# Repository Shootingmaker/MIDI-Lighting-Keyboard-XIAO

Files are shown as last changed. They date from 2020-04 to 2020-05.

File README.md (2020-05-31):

# MIDI-Lighting-Keyboard-XIAO  
  
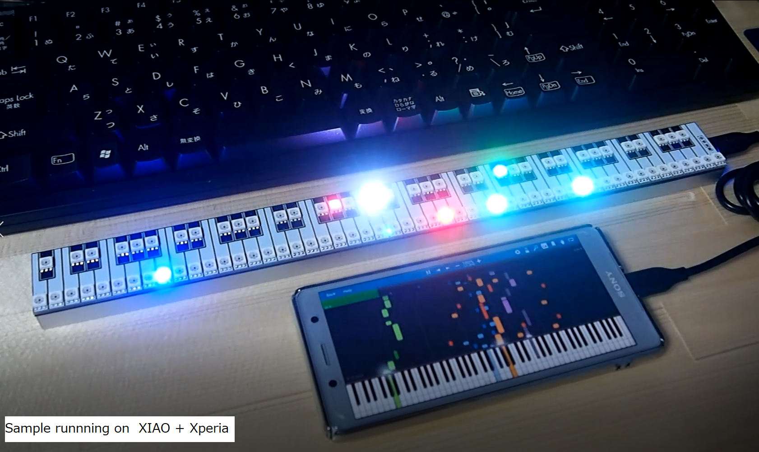
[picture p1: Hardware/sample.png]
Sample
 

(https://www.youtube.com/watch?v=Ko7Av_kq-fI)
This repository for like this video.  
  
1.[Board setting]  
File ->>> Enviroment ->>> add URL  
https://files.seeedstudio.com/arduino/package_seeeduino_boards_index.json  
 
 [Tool ->>> Setting]   
Board : Seed Studio XIAO  
USB stack : Arduino  
Debug:off  
 
2.[Library Install]  
FastLED 3.3.3 "5kft" fork.  
Tools -> Library manager.  
https://github.com/5kft/FastLED/tree/platform-xiao  
 
Arduiono MIDI 5.0  
Tools -> Library manager.  
https://github.com/FortySevenEffects/arduino_midi_library  
 
Arduino USB-MIDI  
Tools -> Library manager.  
https://github.com/lathoub/Arduino-USBMIDI  
 
MIDIUSB  
Tools -> Library manager.  
https://github.com/arduino-libraries/MIDIUSB  
 
3.[Over write "buffer memory" & "RunningStatus" setting.]  
 
 "midi_Settings.h" over write or  USE static  const  
 -> static const unsigned SysExMaxSize = 10240;  // more is better.  
 -> static const bool UseRunningStatus = true;  

4.[HARDWARE Wireing to LED (SK9822 or APA102)]  
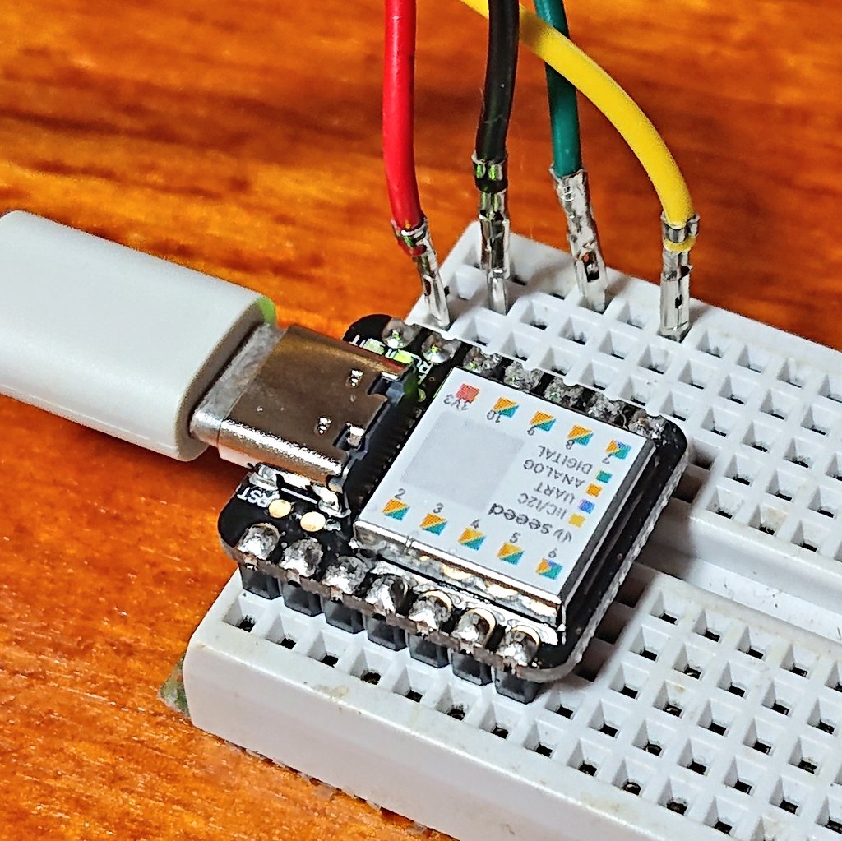
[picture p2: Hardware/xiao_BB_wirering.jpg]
pin

  
 5V    with Capacitor 100uF is Better.  
 SDI(Serial DATA In = MOSI) is  Pin:10(XIAO)  
 CKI(Clock In)  is  Pin:8(XIAO)  
 GND

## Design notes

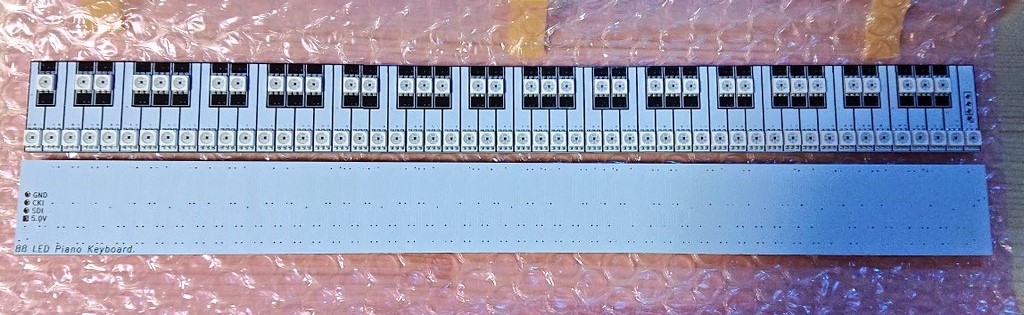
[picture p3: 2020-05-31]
Hardware/PCB_pic.jpg

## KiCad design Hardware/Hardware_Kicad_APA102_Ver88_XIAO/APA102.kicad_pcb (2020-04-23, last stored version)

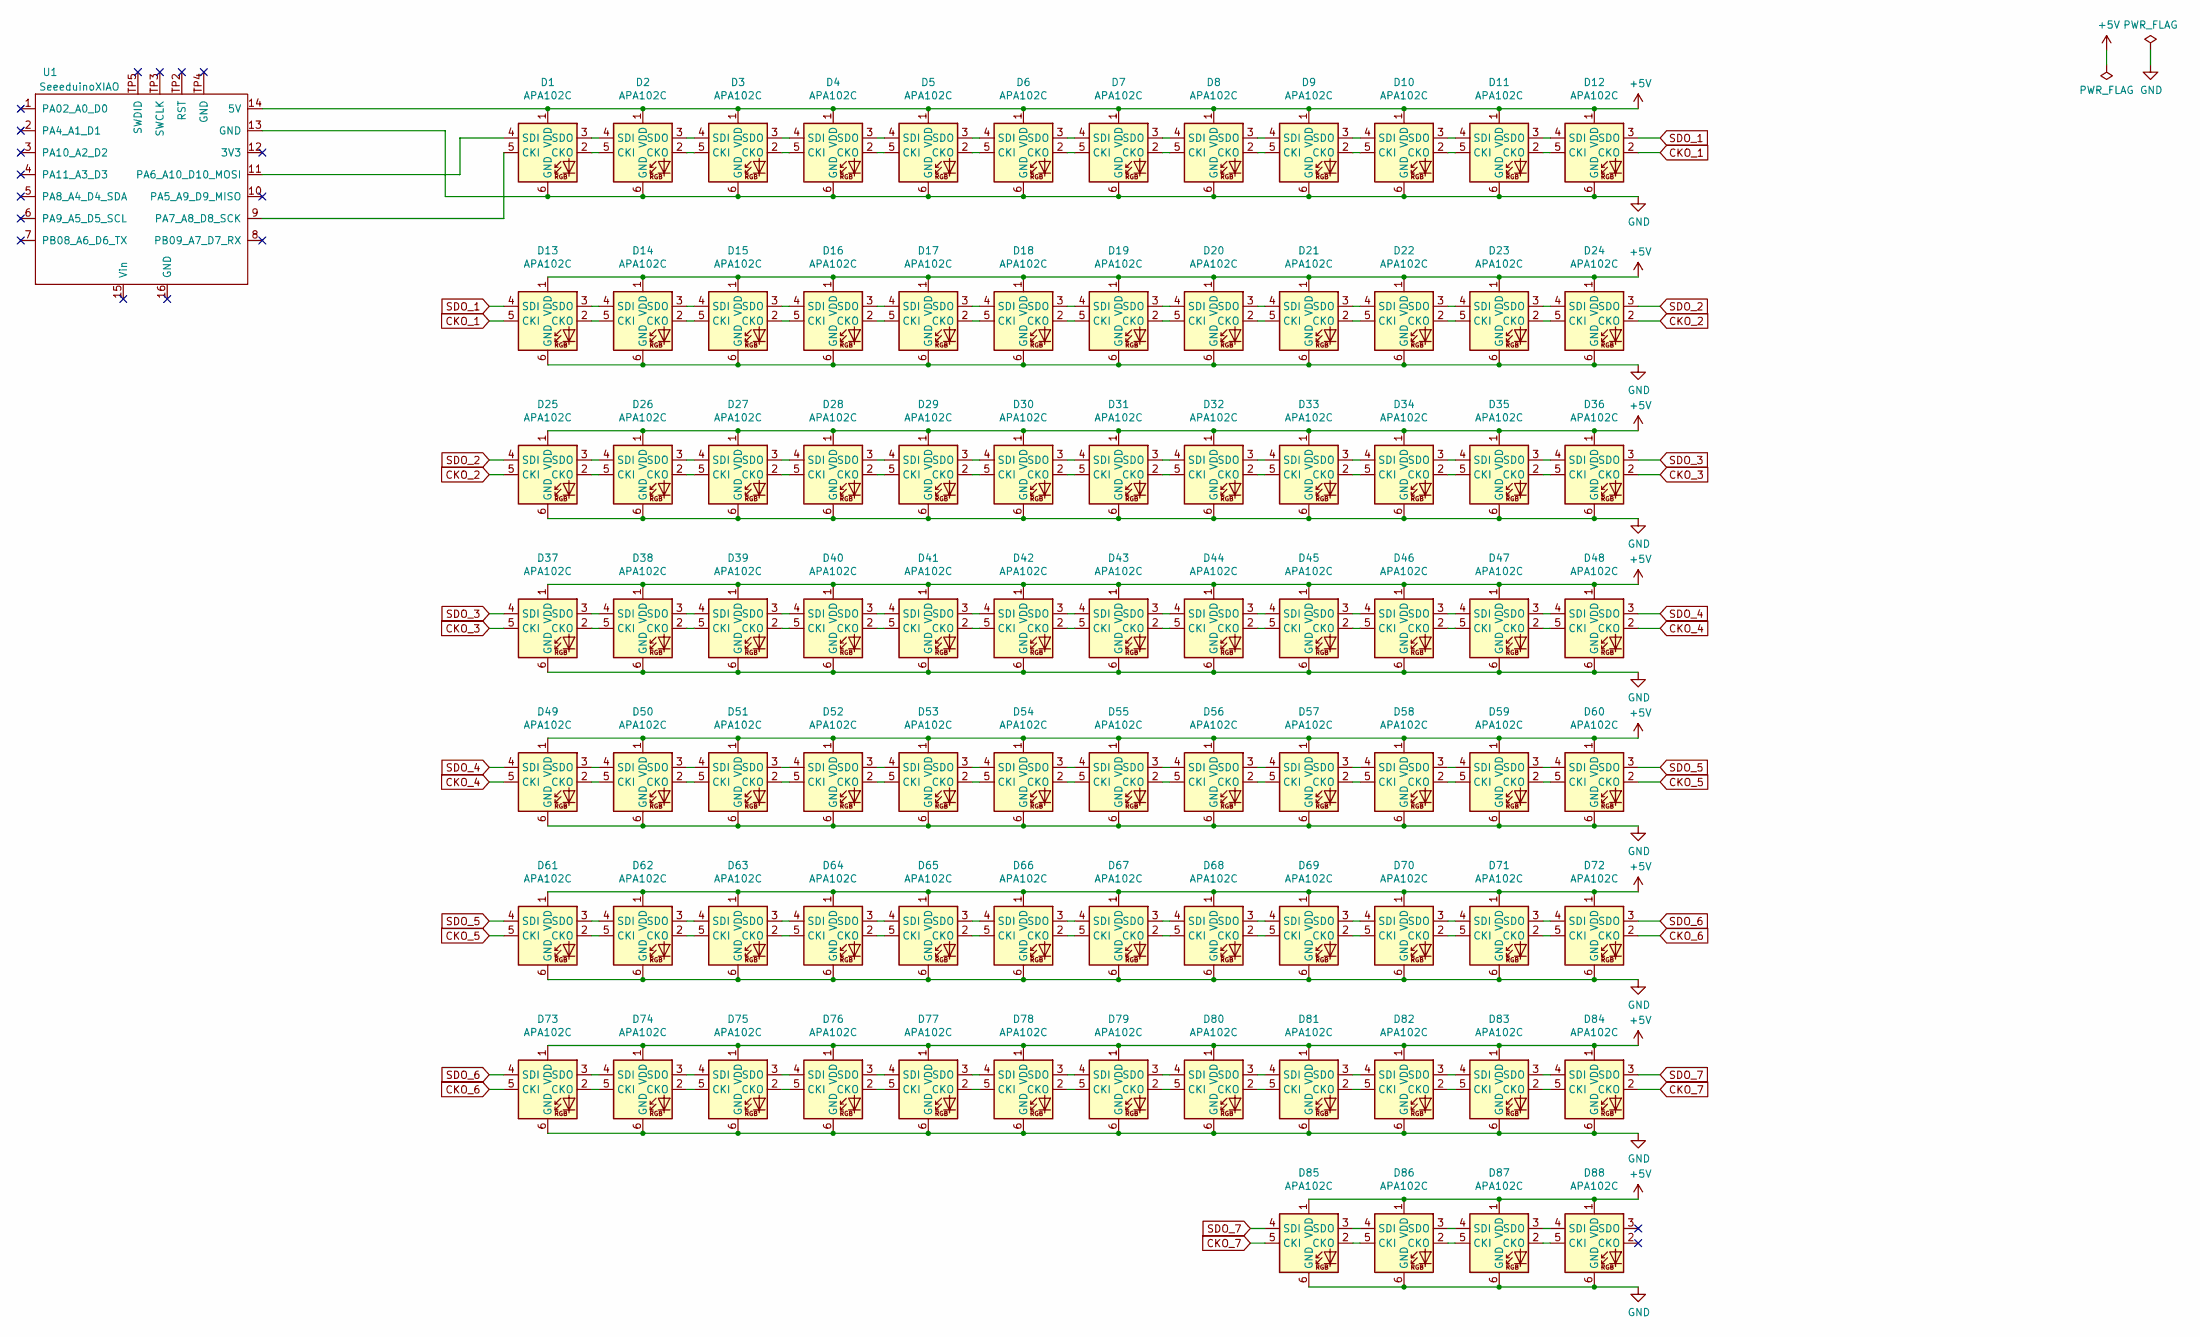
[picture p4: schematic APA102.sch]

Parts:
D1, D2, D3, D4, D5, D6, D7, D8, D9, D10, D11, D12, D13, D14, D15, D16, D17, D18, D19, D20, D21, D22, D23, D24, D25, D26, D27, D28, D29, D30, D31, D32, D33, D34, D35, D36, D37, D38, D39, D40, D41, D42, D43, D44, D45, D46, D47, D48, D49, D50, D51, D52, D53, D54, D55, D56, D57, D58, D59, D60, D61, D62, D63, D64, D65, D66, D67, D68, D69, D70, D71, D72, D73, D74, D75, D76, D77, D78, D79, D80, D81, D82, D83, D84, D85, D86, D87, D88: APA102C; LED_RGB_5050-6B
U1: SeeeduinoXIAO; Seeeduino XIAO-MOUDLE14P-2.54-21X17.8MM

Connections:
+5V: D1.1 (VDD), D2.1 (VDD), D3.1 (VDD), D4.1 (VDD), D5.1 (VDD), D6.1 (VDD), D7.1 (VDD), D8.1 (VDD), D9.1 (VDD), D10.1 (VDD), D11.1 (VDD), D12.1 (VDD), D13.1 (VDD), D14.1 (VDD), D15.1 (VDD), D16.1 (VDD), D17.1 (VDD), D18.1 (VDD), D19.1 (VDD), D20.1 (VDD), D21.1 (VDD), D22.1 (VDD), D23.1 (VDD), D24.1 (VDD), D25.1 (VDD), D26.1 (VDD), D27.1 (VDD), D28.1 (VDD), D29.1 (VDD), D30.1 (VDD), D31.1 (VDD), D32.1 (VDD), D33.1 (VDD), D34.1 (VDD), D35.1 (VDD), D36.1 (VDD), D37.1 (VDD), D38.1 (VDD), D39.1 (VDD), D40.1 (VDD), D41.1 (VDD), D42.1 (VDD), D43.1 (VDD), D44.1 (VDD), D45.1 (VDD), D46.1 (VDD), D47.1 (VDD), D48.1 (VDD), D49.1 (VDD), D50.1 (VDD), D51.1 (VDD), D52.1 (VDD), D53.1 (VDD), D54.1 (VDD), D55.1 (VDD), D56.1 (VDD), D57.1 (VDD), D58.1 (VDD), D59.1 (VDD), D60.1 (VDD), D61.1 (VDD), D62.1 (VDD), D63.1 (VDD), D64.1 (VDD), D65.1 (VDD), D66.1 (VDD), D67.1 (VDD), D68.1 (VDD), D69.1 (VDD), D70.1 (VDD), D71.1 (VDD), D72.1 (VDD), D73.1 (VDD), D74.1 (VDD), D75.1 (VDD), D76.1 (VDD), D77.1 (VDD), D78.1 (VDD), D79.1 (VDD), D80.1 (VDD), D81.1 (VDD), D82.1 (VDD), D83.1 (VDD), D84.1 (VDD), D85.1 (VDD), D86.1 (VDD), D87.1 (VDD), D88.1 (VDD), U1.14 (5V); also elsewhere on the board
CKO_1: D12.2 (CKO), D13.5 (CKI)
CKO_2: D24.2 (CKO), D25.5 (CKI)
CKO_3: D36.2 (CKO), D37.5 (CKI)
CKO_4: D48.2 (CKO), D49.5 (CKI)
CKO_5: D60.2 (CKO), D61.5 (CKI)
CKO_6: D72.2 (CKO), D73.5 (CKI)
CKO_7: D84.2 (CKO), D85.5 (CKI)
GND: D1.6 (GND), D2.6 (GND), D3.6 (GND), D4.6 (GND), D5.6 (GND), D6.6 (GND), D7.6 (GND), D8.6 (GND), D9.6 (GND), D10.6 (GND), D11.6 (GND), D12.6 (GND), D13.6 (GND), D14.6 (GND), D15.6 (GND), D16.6 (GND), D17.6 (GND), D18.6 (GND), D19.6 (GND), D20.6 (GND), D21.6 (GND), D22.6 (GND), D23.6 (GND), D24.6 (GND), D25.6 (GND), D26.6 (GND), D27.6 (GND), D28.6 (GND), D29.6 (GND), D30.6 (GND), D31.6 (GND), D32.6 (GND), D33.6 (GND), D34.6 (GND), D35.6 (GND), D36.6 (GND), D37.6 (GND), D38.6 (GND), D39.6 (GND), D40.6 (GND), D41.6 (GND), D42.6 (GND), D43.6 (GND), D44.6 (GND), D45.6 (GND), D46.6 (GND), D47.6 (GND), D48.6 (GND), D49.6 (GND), D50.6 (GND), D51.6 (GND), D52.6 (GND), D53.6 (GND), D54.6 (GND), D55.6 (GND), D56.6 (GND), D57.6 (GND), D58.6 (GND), D59.6 (GND), D60.6 (GND), D61.6 (GND), D62.6 (GND), D63.6 (GND), D64.6 (GND), D65.6 (GND), D66.6 (GND), D67.6 (GND), D68.6 (GND), D69.6 (GND), D70.6 (GND), D71.6 (GND), D72.6 (GND), D73.6 (GND), D74.6 (GND), D75.6 (GND), D76.6 (GND), D77.6 (GND), D78.6 (GND), D79.6 (GND), D80.6 (GND), D81.6 (GND), D82.6 (GND), D83.6 (GND), D84.6 (GND), D85.6 (GND), D86.6 (GND), D87.6 (GND), D88.6 (GND), U1.13 (GND); also elsewhere on the board
unnamed: D1.2 (CKO), D2.5 (CKI)
unnamed: D1.3 (SDO), D2.4 (SDI)
unnamed 11: D1.4 (SDI), U1.11 (PA6_A10_D10_MOSI); also elsewhere on the board
unnamed 12: D1.5 (CKI), U1.9 (PA7_A8_D8_SCK); also elsewhere on the board
unnamed: D2.2 (CKO), D3.5 (CKI)
unnamed: D2.3 (SDO), D3.4 (SDI)
unnamed: D3.2 (CKO), D4.5 (CKI)
unnamed: D3.3 (SDO), D4.4 (SDI)
unnamed: D4.2 (CKO), D5.5 (CKI)
unnamed: D4.3 (SDO), D5.4 (SDI)
unnamed: D5.2 (CKO), D6.5 (CKI)
unnamed: D5.3 (SDO), D6.4 (SDI)
unnamed: D6.2 (CKO), D7.5 (CKI)
unnamed: D6.3 (SDO), D7.4 (SDI)
unnamed: D7.2 (CKO), D8.5 (CKI)
unnamed: D7.3 (SDO), D8.4 (SDI)
unnamed: D8.2 (CKO), D9.5 (CKI)
unnamed: D8.3 (SDO), D9.4 (SDI)
unnamed: D10.2 (CKO), D11.5 (CKI)
unnamed: D10.3 (SDO), D11.4 (SDI)
unnamed: D9.3 (SDO), D10.4 (SDI)
unnamed: D9.2 (CKO), D10.5 (CKI)
unnamed: D11.2 (CKO), D12.5 (CKI)
unnamed: D11.3 (SDO), D12.4 (SDI)
unnamed: D13.2 (CKO), D14.5 (CKI)
unnamed: D13.3 (SDO), D14.4 (SDI)
unnamed: D14.2 (CKO), D15.5 (CKI)
unnamed: D14.3 (SDO), D15.4 (SDI)
unnamed: D15.2 (CKO), D16.5 (CKI)
unnamed: D15.3 (SDO), D16.4 (SDI)
unnamed: D16.2 (CKO), D17.5 (CKI)
unnamed: D16.3 (SDO), D17.4 (SDI)
unnamed: D17.2 (CKO), D18.5 (CKI)
unnamed: D17.3 (SDO), D18.4 (SDI)
unnamed: D18.2 (CKO), D19.5 (CKI)
unnamed: D18.3 (SDO), D19.4 (SDI)
unnamed: D19.2 (CKO), D20.5 (CKI)
unnamed: D19.3 (SDO), D20.4 (SDI)
unnamed: D20.2 (CKO), D21.5 (CKI)
unnamed: D20.3 (SDO), D21.4 (SDI)
unnamed: D21.2 (CKO), D22.5 (CKI)
unnamed: D21.3 (SDO), D22.4 (SDI)
unnamed: D22.2 (CKO), D23.5 (CKI)
unnamed: D22.3 (SDO), D23.4 (SDI)
unnamed: D23.2 (CKO), D24.5 (CKI)
unnamed: D23.3 (SDO), D24.4 (SDI)
unnamed: D25.2 (CKO), D26.5 (CKI)
unnamed: D25.3 (SDO), D26.4 (SDI)
unnamed: D26.2 (CKO), D27.5 (CKI)
unnamed: D26.3 (SDO), D27.4 (SDI)
unnamed: D27.2 (CKO), D28.5 (CKI)
unnamed: D27.3 (SDO), D28.4 (SDI)
unnamed: D28.2 (CKO), D29.5 (CKI)
unnamed: D28.3 (SDO), D29.4 (SDI)
unnamed: D29.2 (CKO), D30.5 (CKI)
unnamed: D29.3 (SDO), D30.4 (SDI)
unnamed: D30.2 (CKO), D31.5 (CKI)
unnamed: D30.3 (SDO), D31.4 (SDI)
unnamed: D31.2 (CKO), D32.5 (CKI)
unnamed: D31.3 (SDO), D32.4 (SDI)
unnamed: D32.2 (CKO), D33.5 (CKI)
unnamed: D32.3 (SDO), D33.4 (SDI)
unnamed: D33.2 (CKO), D34.5 (CKI)
unnamed: D33.3 (SDO), D34.4 (SDI)
unnamed: D34.2 (CKO), D35.5 (CKI)
unnamed: D34.3 (SDO), D35.4 (SDI)
unnamed: D35.2 (CKO), D36.5 (CKI)
unnamed: D35.3 (SDO), D36.4 (SDI)
unnamed: D37.2 (CKO), D38.5 (CKI)
unnamed: D37.3 (SDO), D38.4 (SDI)
unnamed: D38.2 (CKO), D39.5 (CKI)
unnamed: D38.3 (SDO), D39.4 (SDI)
unnamed: D39.2 (CKO), D40.5 (CKI)
unnamed: D39.3 (SDO), D40.4 (SDI)
unnamed: D40.2 (CKO), D41.5 (CKI)
unnamed: D40.3 (SDO), D41.4 (SDI)
unnamed: D41.2 (CKO), D42.5 (CKI)
unnamed: D41.3 (SDO), D42.4 (SDI)
unnamed: D42.2 (CKO), D43.5 (CKI)
unnamed: D42.3 (SDO), D43.4 (SDI)
unnamed: D43.2 (CKO), D44.5 (CKI)
unnamed: D43.3 (SDO), D44.4 (SDI)
unnamed: D44.2 (CKO), D45.5 (CKI)
unnamed: D44.3 (SDO), D45.4 (SDI)
unnamed: D45.2 (CKO), D46.5 (CKI)
unnamed: D45.3 (SDO), D46.4 (SDI)
unnamed: D46.2 (CKO), D47.5 (CKI)
unnamed: D46.3 (SDO), D47.4 (SDI)
unnamed: D47.2 (CKO), D48.5 (CKI)
unnamed: D47.3 (SDO), D48.4 (SDI)
unnamed: D49.2 (CKO), D50.5 (CKI)
unnamed: D49.3 (SDO), D50.4 (SDI)
unnamed: D50.2 (CKO), D51.5 (CKI)
unnamed: D50.3 (SDO), D51.4 (SDI)
unnamed: D51.2 (CKO), D52.5 (CKI)
unnamed: D51.3 (SDO), D52.4 (SDI)
unnamed: D52.2 (CKO), D53.5 (CKI)
unnamed: D52.3 (SDO), D53.4 (SDI)
unnamed: D53.2 (CKO), D54.5 (CKI)
unnamed: D53.3 (SDO), D54.4 (SDI)
unnamed: D54.2 (CKO), D55.5 (CKI)
unnamed: D54.3 (SDO), D55.4 (SDI)
unnamed: D55.2 (CKO), D56.5 (CKI)
unnamed: D55.3 (SDO), D56.4 (SDI)
unnamed: D56.2 (CKO), D57.5 (CKI)
unnamed: D56.3 (SDO), D57.4 (SDI)
unnamed: D57.2 (CKO), D58.5 (CKI)
unnamed: D57.3 (SDO), D58.4 (SDI)
unnamed: D58.2 (CKO), D59.5 (CKI)
unnamed: D58.3 (SDO), D59.4 (SDI)
unnamed: D59.2 (CKO), D60.5 (CKI)
unnamed: D59.3 (SDO), D60.4 (SDI)
unnamed: D61.2 (CKO), D62.5 (CKI)
unnamed: D61.3 (SDO), D62.4 (SDI)
unnamed: D62.2 (CKO), D63.5 (CKI)
unnamed: D62.3 (SDO), D63.4 (SDI)
unnamed: D63.2 (CKO), D64.5 (CKI)
unnamed: D63.3 (SDO), D64.4 (SDI)
unnamed: D64.2 (CKO), D65.5 (CKI)
unnamed: D64.3 (SDO), D65.4 (SDI)
unnamed: D65.2 (CKO), D66.5 (CKI)
unnamed: D65.3 (SDO), D66.4 (SDI)
unnamed: D66.2 (CKO), D67.5 (CKI)
unnamed: D66.3 (SDO), D67.4 (SDI)
unnamed: D67.2 (CKO), D68.5 (CKI)
unnamed: D67.3 (SDO), D68.4 (SDI)
unnamed: D68.2 (CKO), D69.5 (CKI)
unnamed: D68.3 (SDO), D69.4 (SDI)
unnamed: D69.2 (CKO), D70.5 (CKI)
unnamed: D69.3 (SDO), D70.4 (SDI)
unnamed: D70.2 (CKO), D71.5 (CKI)
unnamed: D70.3 (SDO), D71.4 (SDI)
unnamed: D71.2 (CKO), D72.5 (CKI)
unnamed: D71.3 (SDO), D72.4 (SDI)
unnamed: D73.2 (CKO), D74.5 (CKI)
unnamed: D73.3 (SDO), D74.4 (SDI)
unnamed: D74.2 (CKO), D75.5 (CKI)
unnamed: D74.3 (SDO), D75.4 (SDI)
unnamed: D75.2 (CKO), D76.5 (CKI)
unnamed: D75.3 (SDO), D76.4 (SDI)
unnamed: D76.2 (CKO), D77.5 (CKI)
unnamed: D76.3 (SDO), D77.4 (SDI)
unnamed: D77.2 (CKO), D78.5 (CKI)
unnamed: D77.3 (SDO), D78.4 (SDI)
unnamed: D78.2 (CKO), D79.5 (CKI)
unnamed: D78.3 (SDO), D79.4 (SDI)
unnamed: D79.2 (CKO), D80.5 (CKI)
unnamed: D79.3 (SDO), D80.4 (SDI)
unnamed: D80.2 (CKO), D81.5 (CKI)
unnamed: D80.3 (SDO), D81.4 (SDI)
unnamed: D81.2 (CKO), D82.5 (CKI)
unnamed: D81.3 (SDO), D82.4 (SDI)
unnamed: D82.2 (CKO), D83.5 (CKI)
unnamed: D82.3 (SDO), D83.4 (SDI)
unnamed: D83.2 (CKO), D84.5 (CKI)
unnamed: D83.3 (SDO), D84.4 (SDI)
unnamed: D85.2 (CKO), D86.5 (CKI)
unnamed: D85.3 (SDO), D86.4 (SDI)
unnamed: D86.2 (CKO), D87.5 (CKI)
unnamed: D86.3 (SDO), D87.4 (SDI)
unnamed: D87.2 (CKO), D88.5 (CKI)
unnamed: D87.3 (SDO), D88.4 (SDI)
SDO_1: D12.3 (SDO), D13.4 (SDI)
SDO_2: D24.3 (SDO), D25.4 (SDI)
SDO_3: D36.3 (SDO), D37.4 (SDI)
SDO_4: D48.3 (SDO), D49.4 (SDI)
SDO_5: D60.3 (SDO), D61.4 (SDI)
SDO_6: D72.3 (SDO), D73.4 (SDI)
SDO_7: D84.3 (SDO), D85.4 (SDI)

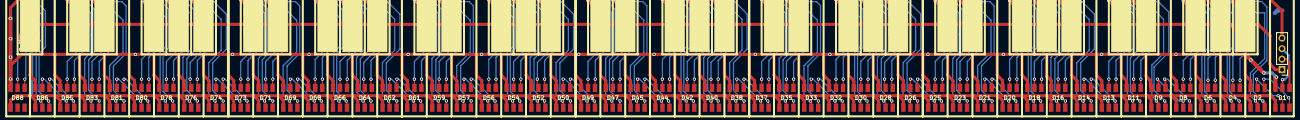
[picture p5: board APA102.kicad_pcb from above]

Board: 2 copper layers, 89 parts (0 on the bottom side), 178 nets.

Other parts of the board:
J1: Conn_01x04_Female; PinHeader_1x04_P2.54mm_Vertical

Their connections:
+5V: J1.1; also elsewhere on the board
GND: J1.4; also elsewhere on the board
unnamed 11: J1.2; also elsewhere on the board
unnamed 12: J1.3; also elsewhere on the board

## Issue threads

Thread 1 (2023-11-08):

No hardware SPI pins defined.  All SPI access will default to bitbanged output

huster-songtao, 2023-11-08:
open MIDI-Lighting-Keyboard_APA102_XIAO_octave_shift_plus_PCB_Revers.ino and modify the code:

```
/* -----------------------------------------------------------------------------
[MIDI Lighting Keyboard Project.]
Kotohiro Masuda. 2020/4/23
-----------------------------------------------------------------------------*/
/*
1.[Board setting]
File ->>> Enviroment ->>> add URL
https://files.seeedstudio.com/arduino/package_seeeduino_boards_index.json

 [Tool ->>> Setting]
Board : Seed Studio XIAO
USB stack : Arduino
Debug:off

2.[Library Install]
FastLED 3.3.3 "5kft" fork.
Tools -> Library manager.
https://github.com/5kft/FastLED/tree/platform-xiao

Arduiono MIDI 5.0
Tools -> Library manager.
https://github.com/FortySevenEffects/arduino_midi_library

Arduino USB-MIDI
Tools -> Library manager.
https://github.com/lathoub/Arduino-USBMIDI

MIDIUSB
Tools -> Library manager.
https://github.com/arduino-libraries/MIDIUSB

3.[Over write "buffer memory" & "RunningStatus" setting.]

 "midi_Settings.h" over write or  USE static  const
 -> static const unsigned SysExMaxSize = 10240;
 -> static const bool UseRunningStatus = true;

4.[HARDWARE Wireing to LED(APA102)]
 5V    with Capacitor 100uF is Better.
 GND
 MOSI is  10
 CLK  is  8

-----------------------------------------------------------------------------*/
static  const  unsigned SysExMaxSize = 1024*28 ;  //1024*24K
static  const  bool UseRunningStatus = true ;

int FastLEDSet_Ch[128];          // Map of Who(channel) use LED?
int octave_shift= 2 *12;           // Shift Octave, if few LEDs. "1"octave=12LEDs.
int Reverse = 127+5 ;

// -----------------------------------------------------------------------------
#include <FastLED.h>

// How many leds in your strip?
#define NUM_LEDS 128
#define DATA_PIN 10
#define CLOCK_PIN 8
#define BRIGHTNESS 24

// Define the array of leds
CRGB leds[NUM_LEDS];

int delayval = 2; // delay for test

// -----------------------------------------------------------------------------

// -----------------------------------------------------------------------------
// LED Blink control.

void handleNoteOn(byte channel, byte pitch, byte velocity)
{
  if (velocity == 0) {  // 　Note ON "Velocity = 0" is NOTE Off.
    leds[pitch].setRGB( 0, 0, 0);
  } else {
    switch (channel) {  //  Select Ch       //　Blink velocity power!
      case 1:
        leds[Reverse-pitch-octave_shift] = CRGB::Green;
        FastLEDSet_Ch[Reverse-pitch-octave_shift]=1;
        break;
      case 2:
        leds[Reverse-pitch-octave_shift] = CRGB::Blue;
        FastLEDSet_Ch[Reverse-pitch-octave_shift]=2;
        break;
      case 3:
        leds[Reverse-pitch-octave_shift] = CRGB::Red;
        FastLEDSet_Ch[Reverse-pitch-octave_shift]=3;
        break;
      case 4:
        leds[Reverse-pitch-octave_shift] = CRGB::Yellow;
        FastLEDSet_Ch[Reverse-pitch-octave_shift]=4;
        break;
      case 5:
        leds[Reverse-pitch-octave_shift] = CRGB::Orange;
        FastLEDSet_Ch[Reverse-pitch-octave_shift]=5;
        break;
      case 6:
        leds[Reverse-pitch-octave_shift] = CRGB::Fuchsia;
        FastLEDSet_Ch[Reverse-pitch-octave_shift]=6;
        break;
      case 7:
        leds[Reverse-pitch-octave_shift] = CRGB::DeepSkyBlue;
        FastLEDSet_Ch[Reverse-pitch-octave_shift]=7;
        break;
      case 8:
        leds[Reverse-pitch-octave_shift] = CRGB::MistyRose;
        FastLEDSet_Ch[Reverse-pitch-octave_shift]=8;
        break;
      case 9:
        leds[Reverse-pitch-octave_shift] = CRGB::GreenYellow;
        FastLEDSet_Ch[Reverse-pitch-octave_shift]=9;
        break;
      case 10:
        leds[Reverse-pitch-octave_shift] = CRGB::DarkBlue;
        FastLEDSet_Ch[Reverse-pitch-octave_shift]=10;
        break;
      case 11:
        leds[Reverse-pitch-octave_shift] = CRGB::Cyan;
        FastLEDSet_Ch[Reverse-pitch-octave_shift]=11;
        break;
      case 12:
        leds[Reverse-pitch-octave_shift] = CRGB::LightCoral;
        FastLEDSet_Ch[Reverse-pitch-octave_shift]=12;
        break;
      case 13:
        leds[Reverse-pitch-octave_shift] = CRGB::Purple;
        FastLEDSet_Ch[Reverse-pitch-octave_shift]=13;
        break;
      case 14:
        leds[Reverse-pitch-octave_shift] = CRGB::FireBrick;
        FastLEDSet_Ch[Reverse-pitch-octave_shift]=14;
        break;
      case 15:
        leds[Reverse-pitch-octave_shift] = CRGB::DeepSkyBlue;
        FastLEDSet_Ch[Reverse-pitch-octave_shift]=15;
        break;
      case 16:
        leds[Reverse-pitch-octave_shift] = CRGB::WhiteSmoke;
        FastLEDSet_Ch[Reverse-pitch-octave_shift]=16;
        break;
    }

  }
      FastLED.show();
}

void handleNoteOff(byte channel, byte pitch, byte velocity)
{
  switch (channel) {
    case 1:
    case 2:
    case 3:
    case 4:
    case 5:
    case 6:
    case 7:
    case 8:
    case 9:
    case 10:
    case 11:
    case 12:
    case 13:
    case 14:
    case 15:
    case 16:
      leds[Reverse-pitch-octave_shift].setRGB( 0, 0, 0); FastLEDSet_Ch[Reverse-pitch-octave_shift]=0;
      FastLED.show();
      break;
  }
}

void handleControlChange(byte channel , byte number , byte value )
{

  switch (number) {
    case 120: for(int i=0;i<NUM_LEDS;i++){leds[i].setRGB( 0, 0, 0);}  break;  // 120 is All sound Off      : All LED OFF
    case 121: for(int i=0;i<NUM_LEDS;i++){leds[i].setRGB( 0, 0, 0);}  break;  // 121 Reset All controller  : All LED OFF
    case 123: for(int i=0;i<NUM_LEDS;i++){leds[i].setRGB( 0, 0, 0);}  break;  // 123 All Note Off         : All LED OFF
   }

  FastLED.show();
}

void setup()
{
    //LED test All On! after OFF
    FastLED.setBrightness (BRIGHTNESS);
    // -----------------------------------------------------------------------------
    FastLED.addLeds<APA102, DATA_PIN, CLOCK_PIN, RGB>(leds, NUM_LEDS);
    //FastLED.addLeds<WS2812, DATA_PIN, RGB>(leds, NUM_LEDS);
    for(int dot = 0; dot < NUM_LEDS; dot++) {
      leds[dot].setRGB( 10, 0, 0);
      FastLED.show();
      // clear this led for the next time around the loop
      delay(delayval); // Delay for a period of time (in milliseconds).
    }

    for(int dot = 0; dot < NUM_LEDS; dot++) {
      leds[dot].setRGB( 0, 10, 0);
      FastLED.show();
      // clear this led for the next time around the loop
      delay(delayval); // Delay for a period of time (in milliseconds).
    }
       
    for(int dot = 0; dot < NUM_LEDS; dot++) {
      leds[dot].setRGB( 0, 0, 10);
      FastLED.show();
      // clear this led for the next time around the loop
      delay(delayval); // Delay for a period of time (in milliseconds).
    }
    
    for(int dot = 0; dot < NUM_LEDS; dot++) {
      leds[dot].setRGB( 0, 0, 0);
      FastLED.show();
      // clear this led for the next time around the loop
      delay(delayval); // Delay for a period of time (in milliseconds).
    }
}

void loop()
{
}

```

Build the code and get the exception:
In file included from d:\Arduino\Sketchbook\libraries\FastLED\src/FastLED.h:75,
                 from D:\Github\MIDI-Lighting-Keyboard-XIAO\Software\MIDI-Lighting-Keyboard_APA102_XIAO_octave_shift_plus_PCB_Revers\MIDI-Lighting-Keyboard_APA102_XIAO_octave_shift_plus_PCB_Revers.ino:54:
d:\Arduino\Sketchbook\libraries\FastLED\src/fastspi.h:157:23: note: '#pragma message: No hardware SPI pins defined.  All SPI access will default to bitbanged output'
  157 | #      pragma message "No hardware SPI pins defined.  All SPI access will default to bitbanged output"
      |                       ^~~~~~~~~~~~~~~~~~~~~~~~~~~~~~~~~~~~~~~~~~~~~~~~~~~~~~~~~~~~~~~~~~~~~~~~~~~~~~~~
d:\Arduino\Sketchbook\libraries\FastLED\src\platforms\esp\32\clockless_rmt_esp32.cpp: In member function 'void ESP32RMTController::startOnChannel(int)':
d:\Arduino\Sketchbook\libraries\FastLED\src\platforms\esp\32\clockless_rmt_esp32.cpp:266:29: error: 'RMTMEM' was not declared in this scope
  266 |         mRMT_mem_start = & (RMTMEM.chan[mRMT_channel].data32[0].val);
      |                             ^~~~~~
d:\Arduino\Sketchbook\libraries\FastLED\src\platforms\esp\32\clockless_rmt_esp32.cpp: In static member function 'static void ESP32RMTController::doneOnChannel(rmt_channel_t, void*)':
d:\Arduino\Sketchbook\libraries\FastLED\src\platforms\esp\32\clockless_rmt_esp32.cpp:347:5: error: 'gpio_matrix_out' was not declared in this scope; did you mean 'gpio_iomux_out'?
  347 |     gpio_matrix_out(pController->mPin, 0x100, 0, 0);
      |     ^~~~~~~~~~~~~~~
      |     gpio_iomux_out

exit status 1

Compilation error: exit status 1

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

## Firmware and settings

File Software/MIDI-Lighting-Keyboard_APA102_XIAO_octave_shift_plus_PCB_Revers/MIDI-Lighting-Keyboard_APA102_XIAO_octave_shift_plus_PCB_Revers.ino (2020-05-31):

/* -----------------------------------------------------------------------------
[MIDI Lighting Keyboard Project.]
Kotohiro Masuda. 2020/4/23
-----------------------------------------------------------------------------*/
/*
1.[Board setting]
File ->>> Enviroment ->>> add URL
https://files.seeedstudio.com/arduino/package_seeeduino_boards_index.json

 [Tool ->>> Setting] 
Board : Seed Studio XIAO
USB stack : Arduino
Debug:off

2.[Library Install]
FastLED 3.3.3 "5kft" fork.
Tools -> Library manager.
https://github.com/5kft/FastLED/tree/platform-xiao

Arduiono MIDI 5.0
Tools -> Library manager.
https://github.com/FortySevenEffects/arduino_midi_library

Arduino USB-MIDI
Tools -> Library manager.
https://github.com/lathoub/Arduino-USBMIDI

MIDIUSB
Tools -> Library manager.
https://github.com/arduino-libraries/MIDIUSB

3.[Over write "buffer memory" & "RunningStatus" setting.]
 
 "midi_Settings.h" over write or  USE static  const
 -> static const unsigned SysExMaxSize = 10240;
 -> static const bool UseRunningStatus = true;


4.[HARDWARE Wireing to LED(APA102)]
 5V    with Capacitor 100uF is Better.
 GND   
 MOSI is  10
 CLK  is  8

-----------------------------------------------------------------------------*/
#include <USB-MIDI.h>
static  const  unsigned SysExMaxSize = 1024*28 ;  //1024*24K
static  const  bool UseRunningStatus = true ; 
USBMIDI_CREATE_DEFAULT_INSTANCE();

int FastLEDSet_Ch[128];          // Map of Who(channel) use LED?
int octave_shift= 2 *12;           // Shift Octave, if few LEDs. "1"octave=12LEDs.
int Reverse = 127+5 ;

// -----------------------------------------------------------------------------
#include <FastLED.h>

// How many leds in your strip?
#define NUM_LEDS 128
#define DATA_PIN 10
#define CLOCK_PIN 8
#define BRIGHTNESS 24

// Define the array of leds
CRGB leds[NUM_LEDS];

int delayval = 2; // delay for test

// -----------------------------------------------------------------------------



// -----------------------------------------------------------------------------
// LED Blink control. 

void handleNoteOn(byte channel, byte pitch, byte velocity)
{
  if (velocity == 0) {  // 　Note ON "Velocity = 0" is NOTE Off.
    leds[pitch].setRGB( 0, 0, 0);
  } else {
    switch (channel) {  //  Select Ch       //　Blink velocity power!
      case 1:
        leds[Reverse-pitch-octave_shift] = CRGB::Green;
        FastLEDSet_Ch[Reverse-pitch-octave_shift]=1;
        break;
      case 2:
        leds[Reverse-pitch-octave_shift] = CRGB::Blue;
        FastLEDSet_Ch[Reverse-pitch-octave_shift]=2;
        break;
      case 3:
        leds[Reverse-pitch-octave_shift] = CRGB::Red;
        FastLEDSet_Ch[Reverse-pitch-octave_shift]=3;
        break;
      case 4:
        leds[Reverse-pitch-octave_shift] = CRGB::Yellow;
        FastLEDSet_Ch[Reverse-pitch-octave_shift]=4;
        break;
      case 5:
        leds[Reverse-pitch-octave_shift] = CRGB::Orange;
        FastLEDSet_Ch[Reverse-pitch-octave_shift]=5;
        break;
      case 6:
        leds[Reverse-pitch-octave_shift] = CRGB::Fuchsia;
        FastLEDSet_Ch[Reverse-pitch-octave_shift]=6;
        break;
      case 7:
        leds[Reverse-pitch-octave_shift] = CRGB::DeepSkyBlue;
        FastLEDSet_Ch[Reverse-pitch-octave_shift]=7;
        break;
      case 8:
        leds[Reverse-pitch-octave_shift] = CRGB::MistyRose;
        FastLEDSet_Ch[Reverse-pitch-octave_shift]=8;
        break; 
      case 9:
        leds[Reverse-pitch-octave_shift] = CRGB::GreenYellow;
        FastLEDSet_Ch[Reverse-pitch-octave_shift]=9;
        break;
      case 10:
        leds[Reverse-pitch-octave_shift] = CRGB::DarkBlue;
        FastLEDSet_Ch[Reverse-pitch-octave_shift]=10;
        break;
      case 11:
        leds[Reverse-pitch-octave_shift] = CRGB::Cyan;
        FastLEDSet_Ch[Reverse-pitch-octave_shift]=11;
        break;
      case 12:
        leds[Reverse-pitch-octave_shift] = CRGB::LightCoral;
        FastLEDSet_Ch[Reverse-pitch-octave_shift]=12;
        break;
      case 13:
        leds[Reverse-pitch-octave_shift] = CRGB::Purple;
        FastLEDSet_Ch[Reverse-pitch-octave_shift]=13;
        break;
      case 14:
        leds[Reverse-pitch-octave_shift] = CRGB::FireBrick;
        FastLEDSet_Ch[Reverse-pitch-octave_shift]=14;
        break;
      case 15:
        leds[Reverse-pitch-octave_shift] = CRGB::DeepSkyBlue;
        FastLEDSet_Ch[Reverse-pitch-octave_shift]=15;
        break;
      case 16:
        leds[Reverse-pitch-octave_shift] = CRGB::WhiteSmoke;
        FastLEDSet_Ch[Reverse-pitch-octave_shift]=16;
        break;        
    }

  }
      FastLED.show();
}

void handleNoteOff(byte channel, byte pitch, byte velocity)
{
  switch (channel) {
    case 1: 
    case 2:
    case 3:
    case 4:
    case 5:
    case 6:
    case 7:
    case 8:
    case 9:
    case 10:
    case 11:
    case 12:
    case 13:
    case 14:
    case 15:
    case 16:
      leds[Reverse-pitch-octave_shift].setRGB( 0, 0, 0); FastLEDSet_Ch[Reverse-pitch-octave_shift]=0;
      FastLED.show();
      break;
  }
}

void handleControlChange(byte channel , byte number , byte value )
{

  switch (number) {
    case 120: for(int i=0;i<NUM_LEDS;i++){leds[i].setRGB( 0, 0, 0);}  break;  // 120 is All sound Off      : All LED OFF
    case 121: for(int i=0;i<NUM_LEDS;i++){leds[i].setRGB( 0, 0, 0);}  break;  // 121 Reset All controller  : All LED OFF
    case 123: for(int i=0;i<NUM_LEDS;i++){leds[i].setRGB( 0, 0, 0);}  break;  // 123 All Note Off         : All LED OFF
   }
  
  FastLED.show();  
}


// -----------------------------------------------------------------------------

void setup()
{

    // -----------------------------------------------------------------------------
    // UsehandleNoteOn Handler with MIDI Library ,after NoteOn Call Back Handler
    MIDI.setHandleNoteOn(handleNoteOn);  //argument is Handler [function].

    // Use NoteOff Handler
    MIDI.setHandleNoteOff(handleNoteOff);

    // Use ControlChange Handler
    MIDI.setHandleControlChange(handleControlChange);

    // All Ch read with MIDI instance initialize.
    MIDI.begin(MIDI_CHANNEL_OMNI);
    // -----------------------------------------------------------------------------

    
    //LED test All On! after OFF
    FastLED.setBrightness (BRIGHTNESS);
    // -----------------------------------------------------------------------------
    FastLED.addLeds<APA102, DATA_PIN, CLOCK_PIN, RGB>(leds, NUM_LEDS);
    //FastLED.addLeds<WS2812, DATA_PIN, RGB>(leds, NUM_LEDS); 
    for(int dot = 0; dot < NUM_LEDS; dot++) { 
            leds[dot].setRGB( 10, 0, 0);
            FastLED.show();
            // clear this led for the next time around the loop
            delay(delayval); // Delay for a period of time (in milliseconds).
            }

    for(int dot = 0; dot < NUM_LEDS; dot++) { 
            leds[dot].setRGB( 0, 10, 0);
            FastLED.show();
            // clear this led for the next time around the loop
            delay(delayval); // Delay for a period of time (in milliseconds).
            }
               
    for(int dot = 0; dot < NUM_LEDS; dot++) { 
            leds[dot].setRGB( 0, 0, 10);
            FastLED.show();
            // clear this led for the next time around the loop
            delay(delayval); // Delay for a period of time (in milliseconds).
            }
            
    for(int dot = 0; dot < NUM_LEDS; dot++) { 
            leds[dot].setRGB( 0, 0, 0);
            FastLED.show();
            // clear this led for the next time around the loop
            delay(delayval); // Delay for a period of time (in milliseconds).
            }

}


void loop()
{
    MIDI.read();    
}

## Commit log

2020-04-23 First version.
    Transfer from teensy based.
2020-04-23 add Hardware
    first comit, just copy.
    DO NOT USE THIS ver NOT WORK!!!!!!
    [APA102-B_Adhes.gbr, APA102-B_CrtYd.gbr, APA102-B_Cu.gbr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]
2020-05-31 add HW pic movie
    Add PCB Picture
    Add sample movie
2020-05-31 Create sample.png
    pic ++
2020-05-31 Update README.md
    change pin discription.
2020-05-31 Create xiao_BB_wirering.jpg
    add wirering pic
2020-05-31 Update README.md
    wire pic
2020-05-31 Update README.md
    set collect pin
